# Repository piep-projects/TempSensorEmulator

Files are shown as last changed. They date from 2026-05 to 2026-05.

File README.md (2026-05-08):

# Wolf CHA-07 Außenfühler-Emulator

Simuliert den NTC-Außentemperaturfühler einer Wolf CHA-07/10/16/20 Monoblock-Wärmepumpe mittels digitalem Potentiometer. Ermöglicht Funktions- und Heizkurvtests unabhängig von der realen Außentemperatur.

→ Vollständige Dokumentation: [PROJECT_OVERVIEW.md](PROJECT_OVERVIEW.md) · [FDS.md](FDS.md)  
→ Projektseite: [projects.v-online.me](https://projects.v-online.me/projekt/wolf-cha-07-ausenfuhler-emulator/)

---

## Hardware

| Komponente | Modell |
|---|---|
| Mikrocontroller | LilyGo T-Display-S3 (ESP32-S3, 1,9" Display) |
| Digitalpotentiometer | Soldered DIGIPOT 50 kΩ nom. (MCP4018T-503, kalibriert ~46 kΩ) |
| Akku | LiPo 3,7 V / 700 mAh |
| Verbindung | I²C über QWIIC-Buchse |

## Verdrahtung

```
T-Display-S3          MCP4018 (DIGIPOT 50K)      Wolf CHA-07
─────────────         ─────────────────────      ─────────────
3,3 V      ────────── VCC
GND        ────────── GND
GPIO 18    ────────── SDA  (QWIIC)
GPIO 17    ────────── SCL  (QWIIC)
                       PW ─────────────────────── Fühler Klemme 1
                       PA ─────────────────────── Fühler Klemme 2
                       PB  offen (nicht auf GND geführt)
```

> **Ausgangspins:** Der Soldered-Breakout führt Pin B (PB) nicht auf GND — der nutzbare
> Widerstandspfad ist **PW ↔ PA**. Messung mit Multimeter ebenfalls an diesen beiden Pins.

## Sensor-Kennlinie

Wolf-Außenfühler Art.-Nr. 2748916 · NTC 5 kΩ bei 25 °C · B = 3977 K *(Schätzwert)*

| Temperatur | Widerstand | MCP4018-Schritt (PW↔PA) |
|---:|---:|---:|
| −15 °C | 39 499 Ω | 18 / 127 |
| −10 °C | 29 476 Ω | 46 / 127 |
| −5 °C | 22 237 Ω | 66 / 127 |
| 0 °C | 16 950 Ω | 81 / 127 |
| +5 °C | 13 047 Ω | 92 / 127 |
| +10 °C | 10 136 Ω | 100 / 127 |
| +20 °C | 6 277 Ω | 111 / 127 |
| +30 °C | 4 013 Ω | 117 / 127 |

## Bedienung

Tasten lösen **beim Loslassen** aus — kein Auto-Repeat.

| Taste | Kurz loslassen (< 3,5 s) | Lang halten + loslassen (≥ 3,5 s) |
|---|---|---|
| **BOOT** (GPIO 0) | −0,5 °C | WLAN-Portal öffnen |
| **KEY** (GPIO 14) | +0,5 °C | Deep Sleep |

Beim langen Halten erfolgt keine Temperaturänderung.

## Flashen

```bash
git clone https://github.com/piep-projects/TempSensorEmulator
cd TempSensorEmulator

# Logo für LittleFS aufbereiten (einmalig, benötigt Pillow)
pip install Pillow
python3 tools/png_to_littlefs.py

pio run -t uploadfs   # LittleFS-Image (Logo)
pio run -t upload     # Firmware
pio device monitor    # Serieller Monitor (115200 Baud)
```

> **16 MB Flash:** Das T-Display-S3 hat 16 MB Flash. Die `platformio.ini` setzt `board_upload.flash_size = 16MB` — ohne diesen Eintrag schlägt `uploadfs` fehl.

**Über die Workbench (RFC2217):**
```bash
pio run -t uploadfs --upload-port 'rfc2217://<host>:<port>'
pio run -t upload   --upload-port 'rfc2217://<host>:<port>'
```

## WLAN einrichten (WiFiManager Captive Portal)

Beim Start verbindet sich das Gerät **still** mit dem gespeicherten Netz (kein Blockieren).  
Das Captive Portal wird **auf Knopfdruck** gestartet:

1. **BOOT-Taste 3,5 s gedrückt halten** → Display zeigt WiFi-Setup-Screen
2. Handy mit **`CHA-Emulator`** (Passwort: `wolf1234`) verbinden
3. Browser öffnet sich **automatisch** → Heimnetz wählen, Passwort eingeben
4. Gerät verbindet sich und startet den Webserver

Danach: Temperatur per Browser unter `http://<IP>` einstellen.

## OTA-Update

Neue Firmware einspielen unter `http://<IP>/update`

## Kompatibilität

| Wärmepumpe | ab Baujahr | Fühler-Art.-Nr. |
|---|---|---|
| Wolf CHA-07 | 10/2018 | 2748916 |
| Wolf CHA-10 | 10/2018 | 2748916 |
| Wolf CHA-16 | 05/2023 | 2748916 |
| Wolf CHA-20 | 05/2023 | 2748916 |

## Projektstruktur

```
TempSensorEmulator/
├── src/
│   ├── main.cpp          # Haupt-Loop, Deep-Sleep, Zustands-Automat
│   ├── display.h/.cpp    # Alle vier Screens + Icons
│   ├── ntc.h             # NTC-Kennlinie, Formel
│   ├── mcp4018.h/.cpp    # I²C-Treiber MCP4018
│   ├── battery.h/.cpp    # ADC, Ladestand, Lade-Erkennung
│   ├── wifi_mgr.h/.cpp   # WiFiManager, Webserver, OTA
│   └── prefs.h/.cpp      # NVS-Persistenz
├── data/
│   └── logo.png          # piep projects Logo (LittleFS, Splash-Screen)
├── mockups/              # Display-Mockups (PNG)
├── datasheets/           # MCP4018-Datenblätter, Logo-Quelle
├── tools/
│   ├── png_to_littlefs.py    # Logo-Konvertierung
│   └── generate_mockups.py   # Screen-Mockups erzeugen
└── platformio.ini
```

*piep projects*

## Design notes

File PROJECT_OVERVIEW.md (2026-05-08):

# Wolf CHA-07 Außenfühler-Emulator — Projektübersicht

**Hersteller:** piep projects  
**Projekt:** TempSensorEmulator  
**Hardware:** LilyGo T-Display-S3 · Soldered DIGIPOT 50 kΩ · LiPo 700 mAh  
**Firmware:** Arduino / PlatformIO  
**Repository:** https://github.com/piep-projects/TempSensorEmulator

---

## Wozu dient dieses Gerät?

Der Außenfühler der Wolf CHA-07/10 Monoblock-Wärmepumpe ist ein passiver NTC-Widerstand (5 kΩ bei 25 °C, Art.-Nr. 2748916). Der Regler liest dessen Widerstand und steuert darüber die Heizkurve.

Dieses Gerät ersetzt den echten Sensor durch ein per Hand einstellbares **digitales Potentiometer**. Damit lässt sich die Wärmepumpe im Labor oder bei der Inbetriebnahme mit beliebigen Außentemperaturen testen — unabhängig vom tatsächlichen Wetter.

**Typische Anwendungsfälle:**
- Heizkurve bei Extremtemperaturen prüfen (z. B. −10 °C im Sommer)
- Regler-Reaktion auf Temperaturänderungen beobachten
- Inbetriebnahme ohne Außenfühler-Anschluss
- Firmware-Entwicklung und Systemtests

---

## Hardware-Übersicht

| Komponente | Modell | Funktion |
|---|---|---|
| Mikrocontroller | LilyGo T-Display-S3 (ESP32-S3) | Steuerung, Display, WiFi |
| Digitalpotentiometer | Soldered DIGIPOT 50 kΩ nom. (MCP4018T-503, kalibriert ~46 kΩ) | NTC-Widerstand simulieren |
| Akku | LiPo 3,7 V / 700 mAh | Mobiler Betrieb |
| Verbindung zum Regler | 2-Draht, an Fühleranschluss Wolf | Ersatz des echten Sensors |

### Pinbelegung (T-Display-S3 → MCP4018)

```
T-Display-S3          MCP4018 (DIGIPOT 50K)      Wolf CHA-07
─────────────         ─────────────────────      ─────────────
3,3 V      ────────── VCC
GND        ────────── GND
GPIO 18    ────────── SDA  (QWIIC)
GPIO 17    ────────── SCL  (QWIIC)
                       PW ─────────────────────── Fühler Klemme 1
                       PA ─────────────────────── Fühler Klemme 2
                       PB  offen (nicht auf GND geführt)
```

> **Ausgangspins:** Der Soldered-Breakout führt Pin B (PB) nicht auf GND — der nutzbare
> Widerstandspfad ist **PW ↔ PA**. Ausgangswiderstand messen: Multimeter an **PW und PA** anlegen
> (nicht PW/GND — Pin B ist nicht zugänglich).

---

## Display-Screens

Das Gerät hat vier Display-Zustände (Mockups in `mockups/`):

| Screen | Datei | Beschreibung |
|---|---|---|
| **Splash** | `screen_splash.png` | piep projects Logo weiß auf schwarz, Firmware-Version |
| **Main** | `screen_main.png` | Temperatur groß, Statusleiste oben, NTC-Info unten |
| **WiFi-Setup** | `screen_wifi_setup.png` | Captive-Portal-Anleitung (SSID, PW, 3 Schritte) |
| **Shutdown** | `screen_shutdown.png` | Roter Warnrahmen, Hinweis auf echten Fühler, Countdown |

---

## Features auf einen Blick

| Feature | Details |
|---|---|
| **Splash-Screen** | piep projects Logo (weiß auf schwarz) + Firmware-Version beim Start |
| **Temperaturanzeige** | −15 °C bis +30 °C, große Anzeige, Schritte 0,5 °C |
| **Tastensteuerung** | Auslösung beim Loslassen · BOOT loslassen < 3,5 s = −0,5 °C · KEY loslassen < 3,5 s = +0,5 °C · kein Auto-Repeat |
| **Deep Sleep** | KEY ≥ 3,5 s halten + loslassen → Stromsparmodus; beliebige Taste → Aufwachen |
| **WiFi on Demand** | BOOT ≥ 3,5 s halten + loslassen → Captive Portal; beim Start nur stilles Reconnect |
| **Batterieanzeige** | Ladestand in % + Icon; Blitz beim Laden |
| **Warnung** | < 15 % rot; < 5 % → automatisch Sleep |
| **Web-Interface** | Temperatur vom Handy/PC einstellen, Status, WLAN-Config |
| **OTA-Update** | Firmware drahtlos über Browser (`/update`) einspielen |
| **NVS-Speicher** | Temperatur + WLAN-Daten bleiben nach Neustart erhalten |

---

## Schnellstart

### 1. Hardware verbinden

Gemäß Verdrahtungstabelle oben. MCP4018 an QWIIC-Buchse des T-Display-S3.  
PW und PA an die Fühleranschlussklemmen der Wolf-Steuerung.

### 2. Firmware flashen

```bash
# Repository klonen
git clone https://github.com/piep-projects/TempSensorEmulator
cd TempSensorEmulator

# Logo für LittleFS vorbereiten (einmalig, benötigt Pillow)
pip install Pillow
python3 tools/png_to_littlefs.py

# LittleFS-Image hochladen
pio run -t uploadfs

# Firmware kompilieren und flashen
pio run -t upload

# Seriellen Monitor (optional, Diagnose)
pio device monitor
```

### 3. WLAN einrichten — WiFiManager Captive Portal

Das WLAN-Portal wird **auf Knopfdruck** gestartet (nicht automatisch beim Boot):

| Parameter | Wert |
|---|---|
| Auslöser | BOOT-Taste **3,5 s** halten |
| SSID | `CHA-Emulator` |
| Passwort | `wolf1234` |

**Ablauf:**
1. BOOT-Taste 3,5 s halten → Display wechselt auf WiFi-Setup-Screen
2. Handy mit `CHA-Emulator` verbinden
3. Browser öffnet sich **automatisch** (Captive Portal, wie Hotel-WLAN)
4. Heimnetz aus der Liste wählen + Passwort eingeben → Gerät verbindet sich

Beim nächsten Start verbindet sich das Gerät **still** mit dem gespeicherten Netz (kein Blockieren, kein Portal).

### 4. Temperatur einstellen

- **Am Gerät:** BOOT kurz drücken und loslassen = −0,5 °C · KEY kurz drücken und loslassen = +0,5 °C
- **Im Browser:** `http://<IP-Adresse>` → Temperatur per Webseite einstellen

### 5. OTA-Firmware-Update

Neue Firmware einspielen unter `http://<IP-Adresse>/update`

---

## Projektstruktur

```
TempSensorEmulator/
├── src/
│   ├── main.cpp              # Haupt-Loop, Zustands-Automat, Deep-Sleep
│   ├── display.h/.cpp        # Alle vier Screens + Icons
│   ├── ntc.h                 # NTC-Kennlinie, Formel
│   ├── mcp4018.h/.cpp        # I²C-Treiber MCP4018
│   ├── battery.h/.cpp        # ADC, Ladestand, Lade-Erkennung
│   ├── wifi_mgr.h/.cpp       # WiFiManager, Webserver, OTA
│   └── prefs.h/.cpp          # NVS-Persistenz
├── data/
│   └── logo.png              # piep projects Logo (LittleFS, Splash-Screen)
├── mockups/
│   ├── screen_splash.png     # Splash-Screen Mockup
│   ├── screen_main.png       # Haupt-Screen Mockup
│   ├── screen_wifi_setup.png # WiFi-Setup-Screen Mockup
│   └── screen_shutdown.png   # Shutdown-Screen Mockup
├── datasheets/
│   ├── piep-logo-projects1.png  # Logo-Quelle (Original)
│   ├── DIGIPOT-10K-MCP4018.pdf
│   └── SOLDERED_MCP4018_DATASHEET.pdf
├── tools/
│   ├── png_to_littlefs.py    # Logo für LittleFS aufbereiten
│   └── generate_mockups.py   # Screen-Mockups erzeugen (benötigt Pillow)
├── platformio.ini
├── README.md                 # Kurzreferenz
├── PROJECT_OVERVIEW.md       # dieses Dokument
├── FDS.md                    # Functional Design Specification
└── FEATURES.md               # Feature-Liste (Planungsphase)
```

---

## Bibliotheken (PlatformIO)

| Bibliothek | PlatformIO-ID | Version | Zweck |
|---|---|---|---|
| LovyanGFX | `lovyan03/LovyanGFX` | ^1.1.16 | Display-Treiber (ST7789, 8080-Bus) |
| WiFiManager | `tzapu/WiFiManager` | ^2.0.17 | WLAN-Konfiguration, Captive Portal |
| ElegantOTA | `ayushsharma82/ElegantOTA` | ^3.1.0 | OTA-Firmware-Update über Browser |
| ArduinoJson | `bblanchon/ArduinoJson` | ^7.0.0 | JSON für `/status`-Endpunkt |

> **Hinweis:** PNG-Dateien aus LittleFS werden per `malloc`/`drawPng()` geladen (kompatibel mit LovyanGFX ≥ 1.2.x).  
> Das T-Display-S3 hat 16 MB Flash — `board_upload.flash_size = 16MB` muss in `platformio.ini` gesetzt sein, da PlatformIO standardmäßig 8 MB annimmt.

---

## Kompatibilität

| Wärmepumpe | Baujahr | Fühler-Art.-Nr. |
|---|---|---|
| Wolf CHA-07 | ab 10/2018 | 2748916 |
| Wolf CHA-10 | ab 10/2018 | 2748916 |
| Wolf CHA-16 | ab 05/2023 | 2748916 |
| Wolf CHA-20 | ab 05/2023 | 2748916 |

---

## Dokumente

| Dokument | Inhalt |
|---|---|
| [README.md](README.md) | Kurzreferenz: Verdrahtung, Flashen, Bedienung |
| [FDS.md](FDS.md) | Functional Design Specification — vollständige technische Spezifikation |
| [FEATURES.md](FEATURES.md) | Feature-Liste der Planungsphase |
| [mockups/](mockups/) | Display-Screen-Mockups (PNG, 960×510) |
| [datasheets/](datasheets/) | MCP4018-Datenblätter, Logo-Quelldatei |

---

## Versionsverlauf

| Version | Datum | Änderungen |
|---|---|---|
| 1.0.0 | 2026-05-06 | Initiale Implementierung — Grundfunktion (NTC-Emulation, Display, Tasten) |
| 1.1.0 | 2026-05-06 | Batterie, Deep Sleep, WiFiManager Captive Portal, Web-Interface, OTA |
| 1.2.0 | 2026-05-06 | WiFi optional (on-demand via BOOT 3,5 s); KEY 3,5 s = Sleep; LittleFS-Fix |
| 1.3.0 | 2026-05-06 | Neues Logo (piep-logo-projects1); überarbeitetes Display-Design (gelbe Farbgebung, Knopf-Beschriftung); Release-Trigger-Tasten (kein Auto-Repeat); Shutdown-Countdown 10 s |
| 1.3.1 | 2026-05-06 | Splash-Logo-Bug behoben (LovyanGFX drawPng-Upscale-Artefakt); Mockup-Generator neu kalibriert (exakte Font-Metriken + Koordinaten) |
| 1.4.0 | 2026-05-07 | Display-Redesign: kein Logo in Kopfzeilen (nur Splash), Screens neu layoutet, Hint-Texte „lang:" statt „3.5s:", I²C-Status per Textfarbe, WiFi/Batterie-Icons vergrößert, Gradzeichen als Superscript |
| 1.4.1 | 2026-05-08 | Bugfix: Widerstandspfad W↔A statt W↔B (Pin B am Soldered-Breakout nicht auf GND); R_AB auf 46 000 Ω kalibriert (gemessen, Nennwert 50 kΩ ±20 %); Genauigkeit ±0,2 °C verifiziert |

---

*piep projects*

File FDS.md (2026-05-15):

# Functional Design Specification
## Wolf CHA-07 Außenfühler-Emulator

| Feld | Wert |
|---|---|
| Dokument | FDS-TempSensorEmulator |
| Version | 1.5 |
| Status | Freigegeben |
| Autor | piep projects |
| Datum | 2026-05-08 |
| Hardware | LilyGo T-Display-S3 · MCP4018T-503 · LiPo 700 mAh |
| Firmware | v1.4.2 |

---

## Inhaltsverzeichnis

1. [Zweck und Geltungsbereich](#1-zweck-und-geltungsbereich)
2. [Abkürzungen und Definitionen](#2-abkürzungen-und-definitionen)
3. [Systemübersicht](#3-systemübersicht)
4. [Hardware-Schnittstellen](#4-hardware-schnittstellen)
5. [Funktionale Anforderungen](#5-funktionale-anforderungen)
6. [Nicht-funktionale Anforderungen](#6-nicht-funktionale-anforderungen)
7. [Software-Architektur](#7-software-architektur)
8. [Zustands-Automat](#8-zustands-automat)
9. [Display-Spezifikation](#9-display-spezifikation)
10. [Web-Interface-Spezifikation](#10-web-interface-spezifikation)
11. [Kommunikations-Schnittstellen](#11-kommunikations-schnittstellen)
12. [Fehlverhalten und Ausnahmen](#12-fehlverhalten-und-ausnahmen)
13. [NTC-Kennlinien-Daten](#13-ntc-kennlinien-daten)
14. [Offene Punkte](#14-offene-punkte)

---

## 1. Zweck und Geltungsbereich

### 1.1 Zweck

Dieses Dokument beschreibt die vollständige funktionale Spezifikation des Wolf CHA-07 Außenfühler-Emulators. Es dient als verbindliche Grundlage für die Firmware-Implementierung.

### 1.2 Geltungsbereich

Das Dokument gilt für Firmware-Version v1.4.2 und die zugehörige Hardware-Revision 1.0.

### 1.3 Zweck des Geräts

Der Außentemperaturfühler der Wolf CHA-07/10/16/20 Monoblock-Wärmepumpe ist ein passiver NTC-Widerstand (5 kΩ bei 25 °C, Art.-Nr. 2748916). Das Gerät ersetzt diesen Sensor durch ein per Benutzer einstellbares digitales Potentiometer und ermöglicht damit Funktionstests des Wärmepumpen-Reglers bei beliebiger simulierter Außentemperatur.

---

## 2. Abkürzungen und Definitionen

| Begriff | Bedeutung |
|---|---|
| ADC | Analog-Digital-Wandler |
| AP | Access Point (WLAN-Hotspot) |
| FDS | Functional Design Specification |
| GPIO | General Purpose Input/Output |
| I²C | Inter-Integrated Circuit (serieller Bus) |
| LiPo | Lithium-Polymer-Akku |
| NTC | Negative Temperature Coefficient (Heißleiter) |
| NVS | Non-Volatile Storage (Flash-Speicher ESP32) |
| OTA | Over-The-Air (drahtloses Firmware-Update) |
| STA | Station Mode (WLAN-Client) |
| QWIIC | SparkFun I²C-Steckersystem (JST 1 mm, 4-polig) |

---

## 3. Systemübersicht

### 3.1 Blockdiagramm

```
┌────────────────────────────────────────────────────────┐
│                  LilyGo T-Display-S3                   │
│                                                        │
│  ┌──────────┐  I²C   ┌───────────────┐                │
│  │ ESP32-S3 │────────│  MCP4018T-503  │──PW──┐         │
│  │          │        │  Digipot 50kΩ  │      │ 2-Draht │
│  │          │        └───────────────┘──PB──┼────────── Wolf CHA-07
│  │          │                               │  Fühler  │
│  │          │  8080   ┌──────────────┐      │           │
│  │          │─────────│  ST7789 TFT  │      │           │
│  │          │         │  1,9"  320×170│      │           │
│  │          │         └──────────────┘      │           │
│  │          │  ADC    ┌──────────────┐      │           │
│  │          │─────────│  LiPo 700mAh │      │           │
│  │          │         │  + Lader     │      │           │
│  │          │         └──────────────┘      │           │
│  │          │  WiFi   ┌──────────────┐      │           │
│  │          │─────────│  802.11 b/g/n│      │           │
│  └──────────┘         └──────────────┘      │           │
│       │                                     │           │
│  GPIO 0 (BOOT)  GPIO 14 (KEY)              │           │
└────────────────────────────────────────────┼───────────┘
                                             │
                               Heizungsregler-Eingang
```

### 3.2 Betriebsmodi

| Modus | Beschreibung |
|---|---|
| Normal | Display an, Tasten aktiv, WiFi verbunden |
| AP-Setup | Kein WLAN konfiguriert; eigener Hotspot aktiv |
| Deep Sleep | Display aus, CPU im Tiefschlaf; Akku geschont |
| Laden | USB angeschlossen; Akku wird geladen; Betrieb normal |

---

## 4. Hardware-Schnittstellen

### 4.1 T-Display-S3 — GPIO-Belegung

| GPIO | Funktion | Richtung | Anmerkung |
|---:|---|---|---|
| 0 | Taste BOOT (−) | Eingang | Active LOW, interner Pull-up |
| 4 | Batterie-ADC | Eingang | Spannungsteiler ÷2 on-board |
| 5 | LCD Reset | Ausgang | Active LOW |
| 6 | LCD CS | Ausgang | |
| 7 | LCD DC | Ausgang | |
| 8 | LCD WR | Ausgang | |
| 9 | LCD RD | Ausgang | |
| 14 | Taste KEY (+) | Eingang | Active LOW, interner Pull-up |
| 15 | LCD Power Enable | Ausgang | Active HIGH |
| 43 | I²C SDA | Ein/Aus | QWIIC / STEMMA QT / EasyC |
| 44 | I²C SCL | Ausgang | QWIIC / STEMMA QT / EasyC |
| 38 | LCD Backlight | Ausgang | PWM, aktiv HIGH |
| 39–48 | LCD Datenbus D0–D7 | Ausgang | 8-Bit parallel 8080 |

### 4.2 MCP4018T-503 — Digitalpotentiometer

| Parameter | Wert |
|---|---|
| Typ | Single-End-Rheostat |
| Nennwiderstand R_AB | 50 000 Ω (kalibriert: 46 000 Ω — gemessen, innerhalb ±20 % Toleranz) |
| Wiper-Widerstand R_W | 75 Ω (typ.) |
| Auflösung | 128 Schritte (7-Bit) |
| I²C-Adresse | 0x2F (fest) |
| Betriebsspannung | 1,8 – 5,5 V (3,3 V) |
| I²C-Takt | 100 kHz |

**Ausgangspins (Soldered-Breakout):**

Der Soldered-Breakout führt Pin B **nicht** auf GND. Der genutzte Widerstandspfad ist
**PW (Wiper) ↔ PA (Terminal A)**. Messung und Heizungsanschluss erfolgen an diesen beiden Pins.
Pin PB bleibt offen.

**Widerstandsformel (W↔A-Pfad):**

```
R_WA(step) = (128 − step) × (R_AB / 128) + R_W
           = (128 − step) × 359,375 Ω + 75 Ω    (mit R_AB = 46 000 Ω)
```

**I²C-Schreibzugriff:**

```
START · 0x2F·WRITE · [step & 0x7F] · STOP
```

### 4.3 Batterie

| Parameter | Wert |
|---|---|
| Zellchemie | LiPo 1S |
| Nennspannung | 3,7 V |
| Kapazität | 700 mAh |
| Ladeschluss | 4,20 V |
| Entladeschluss | 3,20 V |
| Messung | GPIO 4 · ADC1 · Teiler ÷2 |
| Lade-Erkennung | USB-Spannung > Batterie-Spannung (Hysterese 0,1 V) |

**Spannungs-zu-Ladezustand-Kennlinie:**

| Spannung | SoC |
|---:|---:|
| 4,20 V | 100 % |
| 4,00 V | 85 % |
| 3,80 V | 60 % |
| 3,60 V | 30 % |
| 3,40 V | 10 % |
| 3,20 V | 0 % |

Interpolation linear zwischen Stützpunkten. Messung alle 10 s, gleitender Mittelwert über 4 Werte.

---

## 5. Funktionale Anforderungen

### FR-01 — Startsequenz

| ID | Anforderung |
|---|---|
| FR-01.1 | Nach dem Einschalten oder Aufwachen aus Deep Sleep zeigt das Gerät den Splash-Screen. |
| FR-01.2 | Der Splash-Screen zeigt das piep projects Logo (aus LittleFS, weiß auf schwarz) zentriert in der oberen Bildschirmhälfte. |
| FR-01.3 | Unterhalb des Logos erscheint der Text „TempSensorEmulator" in Gelb, darunter die Firmware-Version in Dunkelgrau. |
| FR-01.4 | Der Splash-Screen bleibt 1,5 Sekunden sichtbar. |
| FR-01.5 | Nach Ablauf der 1,5 Sekunden wechselt das Gerät selbstständig in den Hauptscreen. |
| FR-01.6 | Beim ersten Start ohne NVS-Daten wird als Starttemperatur +10,0 °C verwendet. |
| FR-01.7 | War ein Wert in NVS gespeichert, wird dieser unmittelbar nach dem Start an den MCP4018 übertragen — noch während des Splash-Screens. |

### FR-02 — Hauptscreen

| ID | Anforderung |
|---|---|
| FR-02.1 | Der Hauptscreen zeigt die aktuelle Simulationstemperatur in großer weißer Monospace-Schrift zentriert. Die Einheit „°C" wird in Gelb daneben angezeigt. |
| FR-02.2 | In der Info-Zeile (unten links) wird der berechnete NTC-Widerstand angezeigt (Gelb). Direkt daneben steht ein farbiger I²C-Statusblock (grün = OK, rot = Fehler) mit Beschriftung „I²C". |
| FR-02.3 | Die Statusleiste (oben) enthält: „TempSensorEmulator" (Gelb) links; WiFi-Balken-Icon + Batterie-Icon + % rechts. Die IP-Adresse wird nicht in der Statusleiste angezeigt. |
| FR-02.4 | Rechts oben (nahe dem physischen + Knopf): „Temp +" in Gelb, darunter „lang: AUS" in Weiß. Rechts unten (nahe dem physischen − Knopf): „Temp −" in Gelb, darunter „lang: WLAN" in Weiß. |
| FR-02.5 | Der Screen wird nach jeder Temperaturänderung vollständig neu gezeichnet. |
| FR-02.6 | Der MCP4018-Schrittwert (0–127) wird nicht mehr auf dem Display angezeigt. |

### FR-03 — Temperaturregelung über Tasten

Tasten-Auslösung erfolgt **beim Loslassen** (Release-Trigger), nicht beim Drücken.  
Es gibt kein Auto-Repeat — pro Drück-/Loslass-Zyklus wird genau eine Aktion ausgeführt.

| ID | Anforderung |
|---|---|
| FR-03.1 | Taste BOOT drücken und loslassen vor 3,5 s: Temperatur um −0,5 °C ändern. |
| FR-03.2 | Taste KEY drücken und loslassen vor 3,5 s: Temperatur um +0,5 °C ändern. |
| FR-03.3 | Wird eine Taste ≥ 3,5 s gehalten und dann losgelassen, wird die Sonderfunktion ausgelöst — keine Temperaturänderung. |
| FR-03.4 | Die Temperatur ist auf den Bereich −15,0 °C bis +30,0 °C begrenzt. |
| FR-03.5 | Jede Temperaturänderung wird sofort an den MCP4018 übertragen. |
| FR-03.6 | Jede Temperaturänderung wird in NVS gespeichert (max. alle 2 s, um Flash-Zyklen zu schonen). |

### FR-04 — NTC-Emulation (MCP4018)

| ID | Anforderung |
|---|---|
| FR-04.1 | Der Ziel-Widerstand wird nach der Steinhart-Hart-vereinfachten B-Formel berechnet: `R = R25 × exp(B × (1/T − 1/T25))` |
| FR-04.2 | Parameter: R25 = 5000 Ω, B = 3977 K, T25 = 298,15 K. |
| FR-04.3 | Der berechnete Widerstand wird in einen MCP4018-Schritt umgerechnet (W↔A-Pfad): `step = round(128 − (R − R_W) × 128 / R_AB)`, begrenzt auf 0–127. |
| FR-04.4 | Nach jedem Schreibzugriff wird der I²C-Rückgabewert geprüft; bei Fehler wird der I²C-Status im Display rot angezeigt. |
| FR-04.5 | Beim Start wird ein I²C-Scan durchgeführt; ist der MCP4018 nicht erreichbar, bleibt der Fehler dauerhaft angezeigt. |

### FR-05 — Persistenz (NVS)

| ID | Anforderung |
|---|---|
| FR-05.1 | Die zuletzt eingestellte Temperatur wird im NVS-Namespace `emulator` unter dem Schlüssel `temp` gespeichert. |
| FR-05.2 | WLAN-SSID und Passwort werden unter `wifi_ssid` und `wifi_pass` gespeichert. |
| FR-05.3 | Fehlt ein NVS-Schlüssel, wird der definierte Standardwert verwendet (Temp: +10,0 °C; WiFi: leer). |

### FR-06 — Deep Sleep / Energiesparmodus

| ID | Anforderung |
|---|---|
| FR-06.1 | Wird die KEY-Taste (+) ≥ 3,5 Sekunden gehalten und losgelassen, wechselt das Gerät in den Deep Sleep. Während des Haltens erfolgt keine Temperaturänderung. |
| FR-06.2 | Vor dem Einschlafen wird die Temperatur in NVS gespeichert. |
| FR-06.3 | Das Display wird vor dem Einschlafen ausgeschaltet (Backlight aus, Power-Enable LOW). |
| FR-06.4 | Das Gerät wacht durch Druck auf eine beliebige Taste auf (GPIO 0 oder GPIO 14 als Wakeup-Quelle). |
| FR-06.5 | Nach dem Aufwachen durchläuft das Gerät die vollständige Startsequenz (FR-01). |
| FR-06.6 | Der MCP4018 verliert im Deep Sleep seinen Zustand nicht (I²C-Pull-ups halten den Bus; Widerstand bleibt). |
| FR-06.7 | Fällt der Akku unter 5 % SoC, wechselt das Gerät automatisch in den Deep Sleep (mit Hinweis auf dem Display). |

### FR-07 — Batterieanzeige

| ID | Anforderung |
|---|---|
| FR-07.1 | Der Ladezustand wird als Prozentangabe und 5-stufiges Icon in der Statusleiste angezeigt. |
| FR-07.2 | Icon-Stufen: 0–20 % (leer), 21–40 %, 41–60 %, 61–80 %, 81–100 % (voll). |
| FR-07.3 | Wird das Gerät über USB geladen, erscheint ein Blitz-Symbol neben dem Batterie-Icon. |
| FR-07.4 | Bei < 15 % SoC blinkt das Icon im Sekundentakt (rot). |
| FR-07.5 | Bei < 5 % SoC erscheint eine Warnmeldung und das Gerät geht nach 10 Sekunden in Deep Sleep. |

### FR-08 — WiFi-Verbindung

Implementierung über **WiFiManager** (Library: `tzapu/WiFiManager`).

| ID | Anforderung |
|---|---|
| FR-08.1 | Das WiFi-Modul wird beim Start **nicht** aktiviert. Das Gerät läuft immer offline bis der Nutzer WiFi explizit startet. |
| FR-08.2 | WiFi wird **nur auf Knopfdruck** gestartet: BOOT-Taste ≥ 3,5 s halten und loslassen. Sind Credentials gespeichert, verbindet sich das Gerät direkt; andernfalls öffnet sich das Captive Portal. |
| FR-08.3 | ~~Entfallen~~ (in FR-08.2 zusammengefasst). |
| FR-08.4 | AP-Parameter: SSID `CHA-Emulator`, Passwort `wolf1234`, IP `192.168.4.1`. |
| FR-08.5 | Das Gerät zeigt während des AP-Modus den WiFi-Setup-Screen (§9.4) mit Verbindungsanleitung. |
| FR-08.6 | Das Handy verbindet sich mit dem AP; der Browser öffnet automatisch das Captive Portal (wie Hotel-WLAN). |
| FR-08.7 | Der Nutzer wählt sein Heimnetz; WiFiManager speichert die Daten; Webserver startet. |
| FR-08.8 | Nach erfolgreicher Verbindung zeigt die Statusleiste die zugewiesene IP-Adresse. |
| FR-08.9 | Im Deep Sleep wird das WiFi-Modul abgeschaltet. |

### FR-09 — Web-Interface

| ID | Anforderung |
|---|---|
| FR-09.1 | Der interne HTTP-Server läuft auf Port 80 (zusätzlich zum WiFiManager-Portal). |
| FR-09.2 | `GET /` liefert eine mobile HTML-Seite mit aktueller Temperatur, Widerstand, Batterie-SoC, Firmware-Version und IP. |
| FR-09.3 | Die HTML-Seite enthält Schaltflächen `[−]` und `[+]` zum Ändern der Temperatur in 0,5-°C-Schritten. |
| FR-09.4 | `GET /set?t=<wert>` setzt die Temperatur (Bereich −15 bis +30, Auflösung 0,5 °C); antwortet mit Redirect auf `/`. |
| FR-09.5 | `GET /status` antwortet mit JSON (siehe §10.2). |
| FR-09.6 | `/update` stellt die ElegantOTA-Seite für OTA-Updates bereit. |
| FR-09.7 | Die HTML-Seite ist mobilgerecht (Schriftgröße, Abstände für Touchbedienung). |

### FR-10 — OTA-Firmware-Update

| ID | Anforderung |
|---|---|
| FR-10.1 | OTA-Updates werden über ElegantOTA unter `http://<IP>/update` bereitgestellt. |
| FR-10.2 | Während des Updates zeigt das Display einen Ladebalken. |
| FR-10.3 | Nach erfolgreichem Update startet das Gerät automatisch neu. |
| FR-10.4 | Bei fehlerhaftem Update bleibt die alte Firmware aktiv (ESP32-Rollback-Mechanismus). |

---

## 6. Nicht-funktionale Anforderungen

### 6.1 Reaktionszeit

| Anforderung | Wert |
|---|---|
| Temperaturänderung → MCP4018-Update | < 50 ms |
| Tastendruck → Display-Update | < 100 ms |
| Web-Request `/set` → Antwort | < 500 ms |
| `/status` JSON-Antwort | < 100 ms |

### 6.2 Energieverbrauch (Schätzwerte)

| Betriebszustand | Strom | Laufzeit bei 700 mAh |
|---|---:|---:|
| Normal (Display an, WiFi) | ~110 mA | ~6,5 h |
| Normal (Display an, kein WiFi) | ~80 mA | ~8,5 h |
| Deep Sleep | ~15 µA | praktisch unbegrenzt |

### 6.3 Umgebungsbedingungen

Das Gerät ist für Innenraumeinsatz (Keller, Technikraum) ausgelegt.  
Betriebstemperatur: 0 °C – 50 °C · Luftfeuchtigkeit: nicht kondensierend.

### 6.4 Zuverlässigkeit

| Anforderung | Wert |
|---|---|
| NTC-Genauigkeit (nach B-Wert-Kalibrierung) | ±1 °C |
| MCP4018-Schritt-Auflösung | 359 Ω/Schritt (R_AB = 46 kΩ) → ±0,3 °C bei 0 °C |
| Messfehler nach Kalibrierung (Kontrollmessung) | ±0,2 °C bei 0 °C und 25 °C |
| I²C-Fehler | 3 Wiederholungsversuche, dann Fehler-Flag |

---

## 7. Software-Architektur

### 7.1 Modulübersicht

```
src/
├── main.cpp          Haupt-Loop · Zustands-Automat · Deep-Sleep-Logik
├── ntc.h             ntcOhm(tempC) · ohmToStep(R) — pure functions, kein State
├── mcp4018.h/.cpp    I²C-Init · mcp4018Set(step) · mcp4018Probe()
├── battery.h/.cpp    batteryReadVolt() · batteryPercent() · batteryCharging()
├── display.h/.cpp    drawSplash() · drawMain(state) · drawShutdown()
├── wifi_mgr.h/.cpp   wifiConnect() · wifiStartAP() · webServerSetup() · otaSetup()
└── prefs.h/.cpp      prefsLoad() · prefsSave() · prefsLoadWifi() · prefsSaveWifi()

data/
└── logo.png          Splash-Logo (LittleFS, 260×158 px, RGB)

tools/
└── png_to_littlefs.py  Logo-Konvertierung (einmalig, benötigt Pillow)
```

### 7.2 Abhängigkeiten (PlatformIO)

```ini
lib_deps =
    lovyan03/LovyanGFX @ ^1.1.16
    tzapu/WiFiManager @ ^2.0.17
    ayushsharma82/ElegantOTA @ ^3.1.0
    bblanchon/ArduinoJson @ ^7.0.0
```

LittleFS und NVS sind Teil des ESP32-Arduino-Frameworks (keine externe Abhängigkeit).

---

## 8. Zustands-Automat

```
        Einschalten / Aufwachen
               │
               ▼
         ┌──────────┐
         │  SPLASH  │ 1,5 s
         └────┬─────┘
              │ automatisch
              ▼
         ┌──────────┐   BOOT 3,5 s ──► ┌──────────────┐
         │   MAIN   │◄────────────────── │  WIFI_SETUP  │
         │          │   nach Portal      │   (AP-Modus) │
         └────┬─────┘                   └──────────────┘
              │ KEY 3,5 s
              │ oder SoC < 5 %
              ▼
         ┌──────────┐
         │  SLEEP   │ Deep Sleep (µA)
         └────┬─────┘
              │ Taste drücken
              └──────► SPLASH
```

Zustandsvariable `AppState` in `main.cpp`:  
`SPLASH → WIFI_SETUP → MAIN → SLEEP` (WiFiManager löst WIFI_SETUP bei Bedarf aus)

---

## 9. Display-Spezifikation

Display: ST7789V · 170 × 320 px · 8-Bit parallel · Rotation 1 (Querformat: 320 × 170)  
Bibliothek: LovyanGFX

### 9.1 Splash-Screen

```
┌────────────────────────────────────────────────────────────────┐  y=0
│                                                                 │
│                   ┌──────────────┐                             │
│                   │  piep  Logo  │  x=100, y=8, 120×73 px     │
│                   │  weiß/schwarz│  (scale 0.46 aus 260×158)  │
│                   └──────────────┘                             │
│                   TempSensorEmulator                           │  Gelb, y=92
│                        v1.3.0                                  │  Dunkelgrau, y=112
└────────────────────────────────────────────────────────────────┘  y=170
```

| Element | Farbe | Position |
|---|---|---|
| Logo (logo.png, LittleFS) | Weiß auf Schwarz | x=100, y=8, 120×73 px (scale 0.46) |
| „TempSensorEmulator" | Gelb | zentriert, y=92 |
| Firmware-Version | Dunkelgrau | zentriert, y=112 |

### 9.2 Hauptscreen

```
┌────────────────────────────────────────────────────────────────┐  y=0
│ [Logo] TempSensorEmulator    ))) 192.168.1.42  🔋 78%  Temp + │  Statusleiste
│                                                       3.5s:AUS │  y=26
├────────────────────────────────────────────────────────────────┤
│                                                                 │
│                      -5.5 °C                                   │  groß, zentriert
│                                                        Temp −  │
│                                                       3.5s:WLAN│  y=148
├────────────────────────────────────────────────────────────────┤
│  R = 22 237 Ω  ■ I²C                                          │  y=148..158
├────────────────────────────────────────────────────────────────┤
└────────────────────────────────────────────────────────────────┘  y=170
```

| Element | Farbe | Anmerkung |
|---|---|---|
| Logo (klein, transparent) | Weiß | Links in Statusleiste |
| „TempSensorEmulator" | Gelb | Rechts neben Logo |
| WiFi-Balken + IP | Weiß | Statusleiste Mitte |
| Batterie-Icon + % | Weiß / Rot (< 15 %) | Statusleiste rechts |
| „Temp +" / „3.5s: AUS" | Gelb / Weiß | Ganz rechts oben (phys. + Knopf) |
| Temperaturwert | Weiß | Groß, zentriert |
| „°C" | Gelb | Proportional zur Temperaturschrift |
| „Temp −" / „3.5s: WLAN" | Gelb / Weiß | Ganz rechts unten (phys. − Knopf) |
| „R = … Ω" | Gelb | Info-Zeile links |
| I²C-Statusblock + „I²C" | Grün/Rot + Gelb | Direkt rechts neben R-Wert |

### 9.3 Shutdown-Screen (vor Deep Sleep)

```
┌────────────────────────────────────────────────────────────────┐  gelber Rahmen
│ [Logo] TempSensorEmulator                                      │
│  ─────────────────────────────────────────────────────────── │
│              Gerät wird ausgeschaltet                          │  Gelb
│  ─────────────────────────────────────────────────────────── │
│         Letzte Temperatur:  −5.5 °C                           │  Grau
│                  Wert gespeichert.                             │  Grau
│  ─────────────────────────────────────────────────────────── │
│            Bitte echten Fühler wieder                          │  Gelb
│              an Heizung anschliessen!                          │  Gelb
│                    Ausschalten in  10 s …                      │  Dunkelgrau
└────────────────────────────────────────────────────────────────┘
```

Anzeige für 10 Sekunden (Countdown sichtbar), dann Deep Sleep.

### 9.4 WiFi-Setup-Screen (Captive Portal aktiv)

Wird angezeigt, solange WiFiManager im AP-Modus auf Konfiguration wartet.

```
┌────────────────────────────────────────────────────────────────┐  blauer Rahmen
│ [Logo] TempSensorEmulator                                      │
│  ─────────────────────────────────────────────────────────── │
│  ))) AP:  CHA-Emulator                                        │
│      PW:  wolf1234                                            │
│  ─────────────────────────────────────────────────────────── │
│  1. Handy mit "CHA-Emulator" verbinden                        │
│  2. Browser öffnet sich automatisch                           │
│  3. Heimnetz wählen + Passwort eingeben                       │
│                    Warte auf Verbindung …                      │
└────────────────────────────────────────────────────────────────┘
```

---

## 10. Web-Interface-Spezifikation

### 10.1 HTML-Hauptseite `GET /`

Responsive HTML5-Seite. Automatischer Refresh alle 10 Sekunden (`<meta http-equiv="refresh">`).

Inhalte:
- Titel „Wolf CHA-07 Außenfühler-Emulator"
- Titel „Wolf CHA-07 Außenfühler-Emulator"
- Aktuelle Temperatur (groß)
- Schaltflächen `[−]` und `[+]` (POST auf `/set`)
- Tabellarische Statuswerte: Widerstand, MCP4018-Schritt, Batterie, Firmware-Version, IP
- Formular zur WLAN-Konfiguration (SSID + Passwort + Schaltfläche „Speichern & Neustart")

### 10.2 JSON-Status `GET /status`

```json
{
  "temp_c":      -5.5,
  "resistance":  22237,
  "step":        57,
  "battery_pct": 78,
  "charging":    false,
  "wifi_ssid":   "MeinNetz",
  "ip":          "192.168.1.42",
  "fw_version":  "v1.2.0",
  "uptime_s":    3600
}
```

### 10.3 Temperatur setzen `GET /set?t=<wert>`

- Parameter `t`: Dezimalzahl, z. B. `-5.5`
- Auflösung: 0,5 °C (Wert wird auf nächsten 0,5-°C-Schritt gerundet)
- Bereich: −15,0 bis +30,0
- Antwort: HTTP 302 Redirect auf `/`
- Fehler (außerhalb Bereich): HTTP 400 mit Fehlermeldung

### 10.4 WLAN-Konfiguration `POST /wifi`

- Body: `ssid=<name>&pass=<passwort>`
- Aktion: In NVS speichern, HTTP 200 mit Hinweis auf Neustart, dann `ESP.restart()`

---

## 11. Kommunikations-Schnittstellen

### 11.1 I²C — MCP4018

| Parameter | Wert |
|---|---|
| Pins | SDA = GPIO 43, SCL = GPIO 44 |
| Frequenz | 100 kHz |
| Adresse | 0x2F (7-Bit, fest) |
| Protokoll | Single-Byte-Write: `[START][0x5E][step][STOP]` |
| Fehlerbehandlung | 3 Retries, danach Fehler-Flag |

### 11.2 ADC — Batterie

| Parameter | Wert |
|---|---|
| Pin | GPIO 4 (ADC1_CH3) |
| Auflösung | 12 Bit (0–4095) |
| Spannungsteiler | ÷2 (on-board) |
| Formel | `U_bat = ADC_raw × 3,3 V / 4095 × 2` |
| Mittelung | 4 Messungen, gleitender Mittelwert |
| Intervall | alle 10 s |

### 11.3 WiFi — HTTP

| Parameter | Wert |
|---|---|
| Standard | 802.11 b/g/n, 2,4 GHz |
| Port | 80 |
| Protokoll | HTTP/1.1 |
| Bibliothek | ESP32 WebServer (Arduino-Framework) |

---

## 12. Fehlverhalten und Ausnahmen

| Fehler | Erkennung | Reaktion |
|---|---|---|
| MCP4018 nicht erreichbar | I²C EndTransmission ≠ 0 | Rote Statusanzeige; 3 Retries; weiter laufen |
| LittleFS mount fehlt | `LittleFS.begin()` false | Splash ohne Logo; Text-Fallback |
| WiFi nicht gestartet | Default-Zustand beim Boot | Offline-Betrieb; Portal/Verbindung per BOOT ≥ 3,5 s |
| Temperatur außerhalb Bereich (Web) | Validierung in `/set` | HTTP 400 |
| Akku kritisch (< 5 %) | SoC-Berechnung | Shutdown-Screen, dann Deep Sleep |
| NVS leer | `nvs_get` not found | Standardwerte verwenden |

---

## 13. NTC-Kennlinien-Daten

**Sensor:** Wolf CHA-07 Außenfühler, Art.-Nr. 2748916  
**Typ:** NTC 5 kΩ bei 25 °C  
**B-Wert:** 3977 K *(Schätzwert — Herstellerangabe nicht veröffentlicht; mit Messung verifizieren)*

Schritte beziehen sich auf den **W↔A-Pfad** mit R_AB = 46 000 Ω (kalibriert).  
Kontrollmessung ergab ±0,2 °C Abweichung bei 0 °C und 25 °C.

| Temperatur | Widerstand | MCP4018-Schritt (W↔A) | Schrittweite* |
|---:|---:|---:|---:|
| −15 °C | 39 499 Ω | 18 | — |
| −10 °C | 29 476 Ω | 46 | ≈ 0,2 °C/Schritt |
| −5 °C | 22 237 Ω | 66 | ≈ 0,3 °C/Schritt |
| 0 °C | 16 950 Ω | 81 | ≈ 0,4 °C/Schritt |
| +5 °C | 13 047 Ω | 92 | ≈ 0,5 °C/Schritt |
| +10 °C | 10 136 Ω | 100 | ≈ 0,7 °C/Schritt |
| +15 °C | 7 943 Ω | 106 | ≈ 0,8 °C/Schritt |
| +20 °C | 6 277 Ω | 111 | ≈ 1,3 °C/Schritt |
| +25 °C | 5 000 Ω | 114 | ≈ 1,5 °C/Schritt |
| +30 °C | 4 013 Ω | 117 | ≈ 1,7 °C/Schritt |

*\* Temperaturauflösung pro MCP4018-Schritt — im relevanten Winterbereich (−10 bis +5 °C) besser als 0,5 °C.*

**Ausgangswiderstand messen:**  
Multimeter an **PW und PA** des Soldered-Breakouts anlegen (nicht PW/GND — Pin B nicht zugänglich).  
Gerät muss eingeschaltet und der MCP4018 per I²C programmiert sein.

**B-Wert verifizieren:**  
Sensor bei bekannter Temperatur (z. B. Eiswasser = 0 °C) mit Multimeter messen.  
Gemessenen Wert R und T = 273,15 K in `B = ln(R/R25) / (1/T − 1/T25)` einsetzen.  
Ergebnis in `ntc.h` als `NTC_B` eintragen.

---

## 14. Offene Punkte

| Nr. | Punkt | Priorität | Status |
|---|---|---|---|
| OP-01 | Wolf NTC B-Wert messtechnisch verifizieren | Hoch | Offen |
| OP-02 | WiFi-Ersteinrichtung | — | **Entschieden: on-demand via BOOT ≥ 3,5 s + Loslassen** |
| OP-02b | Laden-Erkennung: GPIO-Pin des Lader-IC prüfen (falls vorhanden) | Mittel | Offen |
| OP-03 | Display-Ausrichtung festlegen (USB-C nach oben oder unten) | Niedrig | Offen |
| OP-04 | Gehäuse / Halterung | Niedrig | Nicht spezifiziert |
| OP-05 | OTA-Passwortschutz (aktuell ohne Passwort) | Niedrig | Bewusst offen |
| OP-06 | Tasten-Verhalten Option B testen (Release-Trigger, kein Auto-Repeat) | Mittel | ✅ Erledigt v1.3.0 |
| OP-07 | Shutdown-Countdown (10 s) in Firmware implementieren und anzeigen | Mittel | ✅ Erledigt v1.3.0 |

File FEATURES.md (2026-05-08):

# Feature-Spezifikation — Wolf CHA-07 Außenfühler-Emulator

> **Hinweis:** Dieses Dokument ist die Planungsgrundlage. Die verbindliche Spezifikation steht in [FDS.md](FDS.md).

Version: 1.4.1  
Hardware: LilyGo T-Display-S3 · MCP4018T-503 (50 kΩ nom., kalibriert ~46 kΩ) · LiPo 700 mAh

---

## 1. Startsequenz

**Splash-Screen** (1,5 Sekunden):
- piep projects Logo (weiß auf schwarz) zentriert in oberer Bildschirmhälfte
- „TempSensorEmulator" in Gelb unterhalb des Logos
- Firmware-Version in Dunkelgrau darunter
- Keine Benutzeraktion erforderlich; danach automatisch → Hauptscreen

---

## 2. Hauptscreen

Layout (Querformat 320 × 170 px):

```
┌──────────────────────────────────────────────────────────────┐
│ TempSensorEmulator            ))) 🔋 78%       Temp +        │  ← Statusleiste
│                                                      lang:AUS│
├──────────────────────────────────────────────────────────────┤
│                                                               │
│                      -5.5 °C                         Temp −  │
│                                                    lang:WLAN │
├──────────────────────────────────────────────────────────────┤
│  R = 22 237 Ω  ■ I²C                                        │  ← Info
└──────────────────────────────────────────────────────────────┘
```

| Element | Beschreibung |
|---|---|
| „TempSensorEmulator" | Gelb; links in Statusleiste |
| Temperatur | Groß, weiß; °C in Gelb; ½-°C-Schritte |
| Widerstand | Berechneter NTC-Wert in Ω (Gelb) |
| I²C-Statusblock | Grün = OK, Rot = Fehler; direkt neben R-Wert |
| WiFi-Symbol | Signal-Balken + IP-Adresse; rot = getrennt |
| Batterie | Icon + Prozent; Blitz-Symbol beim Laden |
| Knopf-Hints | „Temp +" / „Temp −" gelb; Langdruck-Funktion weiß |

---

## 3. Temperaturregelung

Tasten lösen **beim Loslassen** aus — kein Auto-Repeat.

| Aktion | Funktion |
|---|---|
| BOOT loslassen (< 3,5 s) | −0,5 °C |
| KEY loslassen (< 3,5 s) | +0,5 °C |
| BOOT ≥ 3,5 s halten + loslassen | WLAN-Portal starten |
| KEY ≥ 3,5 s halten + loslassen | Deep Sleep |
| Bereich | −15 °C bis +30 °C |

Beim langen Halten erfolgt keine Temperaturänderung.  
Eingestellte Temperatur wird sofort an MCP4018 übertragen.  
Wert wird im Flash (NVS) gespeichert und nach Neustart wiederhergestellt.

---

## 4. Ein / Aus (Deep Sleep)

| Aktion | Funktion |
|---|---|
| KEY ≥ 3,5 s halten + loslassen | Shutdown-Screen (10 s), dann Deep Sleep |
| Beliebige Taste drücken | Aufwachen, Splash → Hauptscreen |

Im Deep Sleep: MCP4018 hält letzten Wert (I²C-Pegel fallen ab → Widerstand undefiniert).  
**Empfehlung:** Heizung vor dem Ausschalten auf echten Sensor umschalten.

---

## 5. Batterie

| Funktion | Details |
|---|---|
| Spannungsmessung | GPIO 4 (ADC, Teiler ÷2 on-board) |
| Ladestand-Anzeige | 0–100 %, 5-stufiges Icon |
| Laden-Erkennung | Spannung > 4,0 V und steigend → Blitz-Symbol |
| Kapazität | 700 mAh LiPo |
| Warnschwelle | < 15 % → Icon rot blinkend |
| Kritisch | < 5 % → automatisch Deep Sleep |

Spannungs-zu-Prozent-Kurve (LiPo typisch):

| Spannung | Ladezustand |
|---:|---:|
| 4,20 V | 100 % |
| 4,00 V | 85 % |
| 3,80 V | 60 % |
| 3,60 V | 30 % |
| 3,40 V | 10 % |
| 3,20 V | 0 % (Schutzabschaltung) |

---

## 6. WiFi

> **Entschieden:** WiFi-Konfiguration über **WiFiManager Captive Portal** (tzapu/WiFiManager).  
> Browser öffnet sich automatisch beim Verbinden mit dem AP — wie Hotel-WLAN.

### Verbindungsaufbau
1. Beim Start: stilles Reconnect (max. 10 s), kein Portal, kein Blockieren
2. Portal **nur auf Knopfdruck**: BOOT ≥ 3,5 s halten + loslassen
   - SSID: `CHA-Emulator`
   - Passwort: `wolf1234`
   - Browser öffnet sich automatisch → Netzauswahl + Passwort → Speichern

### Web-Interface (Port 80)

Aufrufbar über IP-Adresse im Browser (Handy oder PC).

**Hauptseite `/`**

```
┌─────────────────────────────────────────────┐
│        piep projects                           │
│   Wolf CHA-07 Außenfühler-Emulator          │
│                                             │
│   Temperatur          [ − ]  -5.5°C  [ + ] │
│   Widerstand          22 237 Ω              │
│   Batterie            78 %  (laden)         │
│   Firmware            v1.0.0                │
│   IP                  192.168.1.42          │
└─────────────────────────────────────────────┘
```

- Seite aktualisiert sich alle 5 Sekunden (auto-refresh)
- `[−]` / `[+]` senden HTTP-GET `/set?t=-6.0`
- Temperatur in 0,5-°C-Schritten einstellbar

**Endpunkte:**

| Endpunkt | Methode | Beschreibung |
|---|---|---|
| `/` | GET | Hauptseite (HTML) |
| `/set?t=<wert>` | GET | Temperatur setzen (−15 bis +30) |
| `/status` | GET | JSON: temp, resistance, step, battery_pct, charging, ip |
| `/update` | GET/POST | OTA-Firmware-Update (ElegantOTA) |

### OTA
- Bibliothek: **ElegantOTA**
- Erreichbar unter `http://<IP>/update`
- Kein Passwort (Gerät ist im lokalen Netz)

---

## 7. Software-Architektur

```
src/
  main.cpp          # Setup, Loop, Zustands-Automat, Deep-Sleep
  display.h/.cpp    # Splash, Main, WiFi-Setup, Shutdown + Icons
  ntc.h             # NTC-Kennlinie, ohmToStep()
  mcp4018.h/.cpp    # I²C-Treiber MCP4018
  battery.h/.cpp    # ADC-Messung, Ladestand, Laden-Erkennung
  wifi_mgr.h/.cpp   # WiFiManager, Web-Server, OTA
  prefs.h/.cpp      # NVS: Temperatur + WiFi-Credentials speichern
data/
  logo.png          # piep projects Logo weiß (für LittleFS)
mockups/
  screen_splash.png
  screen_main.png
  screen_wifi_setup.png
  screen_shutdown.png
```

---

## 8. Firmware-Versionsschema

`MAJOR.MINOR.PATCH` — z. B. `v1.3.0`  
Definiert als `#define FW_VERSION "v1.4.1"` in `config.h`.

---

## 9. Offene Punkte / Entscheidungen

| Punkt | Status |
|---|---|
| Wolf NTC B-Wert verifizieren | offen — Messung ausstehend |
| WiFi-Ersteinrichtung | ✅ WiFiManager Captive Portal |
| Display-Screens | ✅ 4 Screens: Splash, Main, WiFi-Setup, Shutdown |
| Logo auf Display | ✅ weiß auf schwarz; nur im Splash-Screen |
| Temperaturanzeige | ✅ große Mono-Schrift, °C in Gelb |
| Display-Ausrichtung (USB oben/unten) | offen — nicht festgelegt |
| Gehäuse / Halterung | nicht spezifiziert |

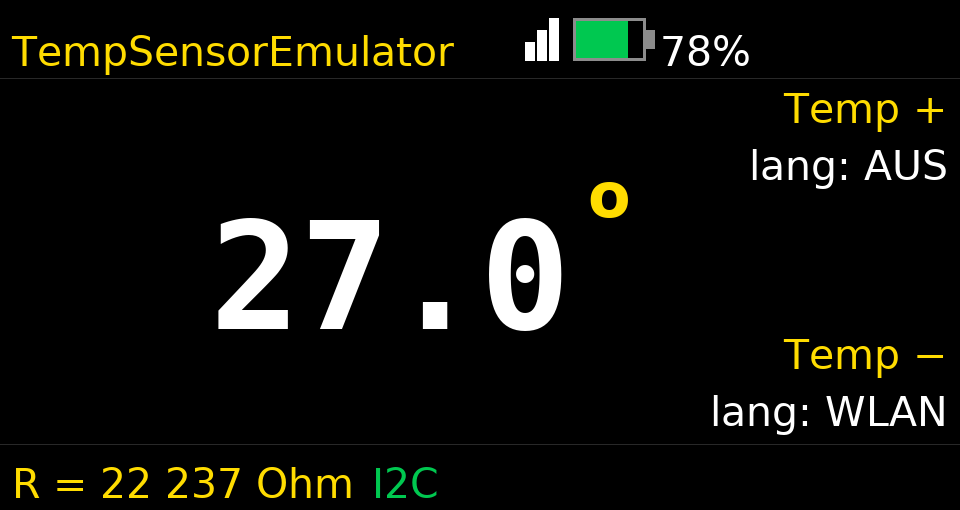
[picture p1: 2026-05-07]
mockups/screen_main.png

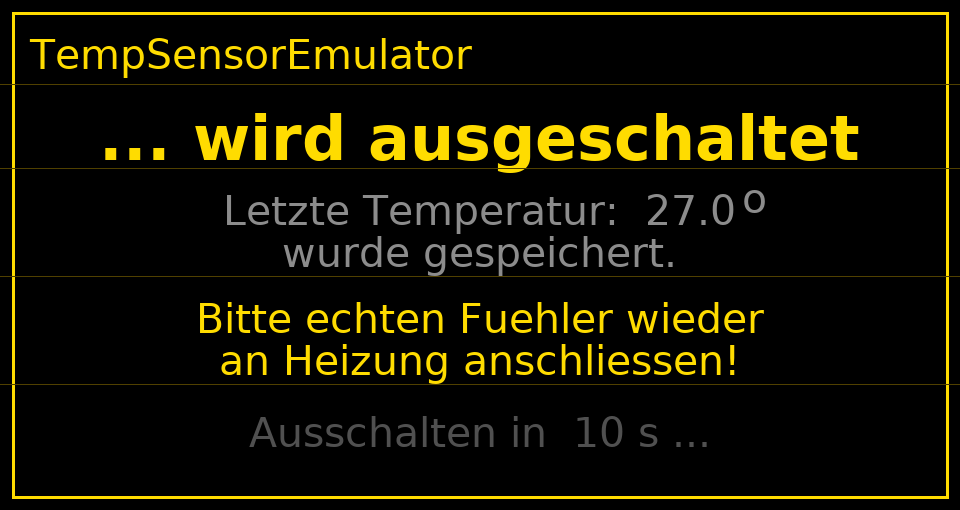
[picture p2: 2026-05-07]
mockups/screen_shutdown.png

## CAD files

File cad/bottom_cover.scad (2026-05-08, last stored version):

// ═══════════════════════════════════════════════════════════════════
//  Wolf CHA-07 Außenfühler-Emulator — DIGIPOT Untergehäuse
//  Datei: cad/bottom_cover.scad
//  Druck: FDM, PETG oder PLA, 0,2 mm Schichthöhe, 3 Wände
// ═══════════════════════════════════════════════════════════════════
//
//  Draufsicht (von unten gesehen):
//
//          Seite D  (kurz, 32 mm)  ← QWIIC-Schlitz
//          ┌──────────────────────┐
//          │                      │
//  Seite A │                      │ Seite C
//  (lang   │                      │ (lang
//  70 mm)  │                      │  70 mm)
//          │                      │
//          └──────────────────────┘
//          Seite B  (kurz, 32 mm)  ← beide Schrauben
//
//  Schrauben: horizontal, von außen durch Seite B, je 1 mm von A und C.
//  QWIIC:     Schlitz in Seite D, Kabel läuft von innen nach außen.

// ───────────────────────────────────────────────────────────────────
//  ❶  LILYGO T-DISPLAY-S3 GREY SHELL
// ───────────────────────────────────────────────────────────────────

shell_w = 70.0;   // [mm] Außenmaß lang  (A↔C, X-Achse)
shell_d = 32.0;   // [mm] Außenmaß kurz  (B↔D, Y-Achse)

// Schrauben auf Seite B — je 1 mm von Seite A bzw. Seite C
screw_ya      =  1.0;             // [mm] Abstand von Seite A  (Y = 1)
screw_yc      =  shell_d - 1.0;  // [mm] Abstand von Seite C  (Y = 31)

// Z-Höhe der Schrauben: wird unten im Berechnungsblock gesetzt.
// Bitte am Gerät nachmessen und ggf. überschreiben.

screw_d       =  2.2;   // [mm] Schaftbohrung M2
screw_head_d  =  4.2;   // [mm] Senkkopf-Ø (M2 = 3,8 mm)
screw_head_h  =  2.0;   // [mm] Senktiefe
boss_d        =  8.0;   // [mm] Boss-Ø (gibt 2,9 mm Wand um M2-Loch)
boss_pad      =  1.5;   // [mm] Boss-Überstand über Seite-B-Außenwand

// ───────────────────────────────────────────────────────────────────
//  ❷  SOLDERED DIGIPOT 50 kΩ (MCP4018T-503)
// ───────────────────────────────────────────────────────────────────

digipot_pcb_w  = 22.0;  // [mm] Platine X
digipot_pcb_d  = 22.0;  // [mm] Platine Y
digipot_pcb_h  =  2.0;  // [mm] Platinenstärke
digipot_comp_h =  5.0;  // [mm] Bauhöhe inkl. QWIIC-Buchse
digipot_margin =  1.5;  // [mm] Luft rund um Platine

// ───────────────────────────────────────────────────────────────────
//  ❸  QWIIC-KABELSCHLITZ  — Seite D (linke Stirnseite)
// ───────────────────────────────────────────────────────────────────

qwiic_slot_w  =  7.0;  // [mm] Breite in Y (Kabel + QWIIC-Buchse)
qwiic_slot_h  =  4.5;  // [mm] Höhe  in Z
// Y-Position: zentriert in Seite D
qwiic_slot_y  =  shell_d / 2 - qwiic_slot_w / 2;
// Z-Position: 1 mm über Bodenwand
qwiic_slot_z  =  wall_t + 1;

// ───────────────────────────────────────────────────────────────────
//  ❹  GEHÄUSE-PARAMETER
// ───────────────────────────────────────────────────────────────────

wall_t    = 2.0;
overlap_h = 3.0;
fit_clear = 0.3;

// ───────────────────────────────────────────────────────────────────
//  BERECHNETE GRÖßEN
// ───────────────────────────────────────────────────────────────────

inner_h = digipot_pcb_h + digipot_comp_h + 3.0;
total_h = inner_h + overlap_h;

// Schraubenhöhe: Kragen-Mitte — ggf. nachmessen und anpassen
screw_z = inner_h + overlap_h / 2;  // [mm]  ← MESSEN

outer_w = shell_w + 2 * wall_t;
outer_d = shell_d + 2 * wall_t;

collar_inner_w = shell_w + 2 * fit_clear;
collar_inner_d = shell_d + 2 * fit_clear;

// Standoff-Koordinaten (Platine zentriert in XY)
so_x0 = (shell_w - digipot_pcb_w) / 2 + digipot_margin * 0.4;
so_y0 = (shell_d - digipot_pcb_d) / 2 + digipot_margin * 0.4;
so_x1 = so_x0 + digipot_pcb_w - digipot_margin * 0.8;
so_y1 = so_y0 + digipot_pcb_d - digipot_margin * 0.8;

// Seite B: Außenfläche bei X = shell_w + wall_t
side_b_outer = shell_w + wall_t;

$fn = 48;

module so(x, y) { translate([x, y, wall_t]) cylinder(d=2.0, h=1.2); }

// ═══════════════════════════════════════════════════════════════════
//  HAUPTKÖRPER
// ═══════════════════════════════════════════════════════════════════

difference() {

    union() {

        // ── Kasten + Kragen, innen ausgehöhlt ──
        difference() {
            union() {
                translate([-wall_t, -wall_t, 0])
                    cube([outer_w, outer_d, inner_h]);
                translate([-wall_t, -wall_t, inner_h])
                    cube([outer_w, outer_d, overlap_h]);
            }
            // Innenraum Kasten
            translate([0, 0, wall_t])
                cube([shell_w, shell_d, inner_h - wall_t + 0.01]);
            // Innenraum Kragen
            translate([-fit_clear, -fit_clear, inner_h])
                cube([collar_inner_w, collar_inner_d, overlap_h + 1]);
        }

        // ── Boss-Zylinder Seite B — beide Schrauben ──
        // Ragen über Seite-B-Außenwand nach rechts (+X) heraus.
        translate([side_b_outer, screw_ya, screw_z])
            rotate([0, 90, 0])
            cylinder(d=boss_d, h=boss_pad);

        translate([side_b_outer, screw_yc, screw_z])
            rotate([0, 90, 0])
            cylinder(d=boss_d, h=boss_pad);

        // ── Standoffs für DIGIPOT-Platine ──
        so(so_x0, so_y0);
        so(so_x1, so_y0);
        so(so_x0, so_y1);
        so(so_x1, so_y1);
    }

    // ── Schraubenlöcher Seite B (von außen nach innen, -X-Richtung) ──
    // Startpunkt liegt 1 mm hinter der Boss-Außenfläche.
    _hole_start_x = side_b_outer + boss_pad + 1;
    _hole_depth   = boss_pad + wall_t - fit_clear + 2;

    translate([_hole_start_x, screw_ya, screw_z])
        rotate([0, -90, 0])
        cylinder(d=screw_d, h=_hole_depth);
    translate([_hole_start_x, screw_ya, screw_z])
        rotate([0, -90, 0])
        cylinder(d=screw_head_d, h=screw_head_h + 1);

    translate([_hole_start_x, screw_yc, screw_z])
        rotate([0, -90, 0])
        cylinder(d=screw_d, h=_hole_depth);
    translate([_hole_start_x, screw_yc, screw_z])
        rotate([0, -90, 0])
        cylinder(d=screw_head_d, h=screw_head_h + 1);

    // ── QWIIC-Schlitz Seite D (linke Stirnwand, -X-Richtung) ──
    translate([-wall_t - 1, qwiic_slot_y, qwiic_slot_z])
        cube([wall_t + 2, qwiic_slot_w, qwiic_slot_h]);
}

// ───────────────────────────────────────────────────────────────────
//  DEBUG: LilyGo-Referenzquader (* entfernen zum Einblenden)
// ───────────────────────────────────────────────────────────────────

*color("SteelBlue", 0.25)
    translate([0, 0, inner_h])
        cube([shell_w, shell_d, 14]);

// ───────────────────────────────────────────────────────────────────
//  SCHRAUBENZUGABE
//  boss_pad + (wall_t − fit_clear) = 1,5 + 1,7 = 3,2 mm
//  Beispiel: originale M2×5 → neue M2×8
// ───────────────────────────────────────────────────────────────────

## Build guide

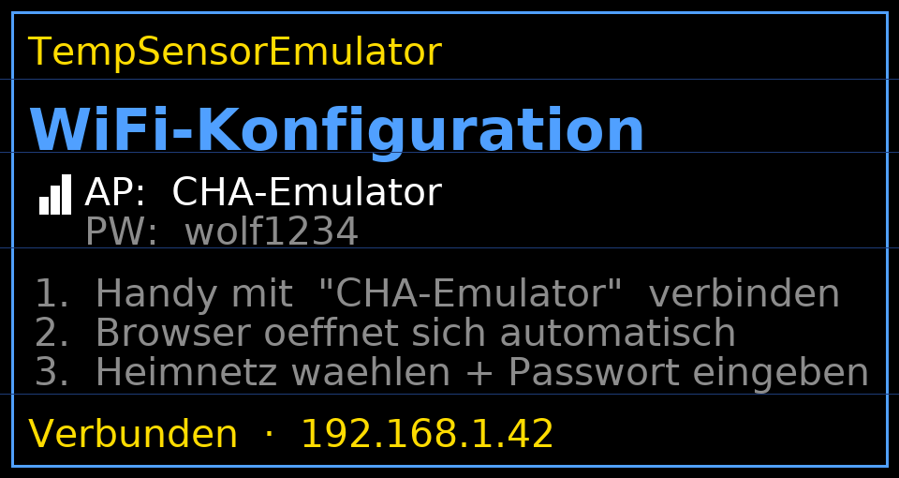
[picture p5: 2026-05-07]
mockups/screen_wifi_setup.png

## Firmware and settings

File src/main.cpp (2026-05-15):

// Wolf CHA-07 Aussenfuhler-Emulator  —  main.cpp
// piep design · v1.3.0

#include <Arduino.h>
#include "config.h"
#include "ntc.h"
#include "mcp4018.h"
#include "battery.h"
#include "prefs.h"
#include "display.h"
#include "wifi_mgr.h"

// ── Zustand ───────────────────────────────────────────────────
static float g_tempC        = TEMP_DEFAULT;
static bool  g_displayDirty = true;

// ── Button-Handling (Option B: Auslösung beim Loslassen) ──────
enum BtnEvent { BTN_NONE, BTN_SHORT, BTN_LONG };

struct Button {
    uint8_t  pin;
    uint32_t pressedAt;   // millis() beim Drücken (0 = nicht gedrückt)
    bool     prevPressed;
};

static Button btnMinus{ PIN_BTN_MINUS, 0, false };
static Button btnPlus { PIN_BTN_PLUS,  0, false };

// Erkennt Kurzdruck (<BTN_ACTION_MS) und Langdruck (>=BTN_ACTION_MS) beim Loslassen.
// Kein Auto-Repeat — eine Aktion pro Tastenbetätigung.
static BtnEvent pollButton(Button& b) {
    bool pressed = (digitalRead(b.pin) == LOW);

    if (pressed && !b.prevPressed) {
        b.pressedAt = millis();
    } else if (!pressed && b.prevPressed && b.pressedAt) {
        uint32_t held = millis() - b.pressedAt;
        b.pressedAt = 0;
        b.prevPressed = false;
        return (held >= BTN_ACTION_MS) ? BTN_LONG : BTN_SHORT;
    }

    b.prevPressed = pressed;
    return BTN_NONE;
}

// ── Sonderfunktionen ──────────────────────────────────────────

static void doSleep() {
    prefsFlush();
    for (int s = SHUTDOWN_COUNTDOWN_S; s >= 0; s--) {
        drawShutdown(g_tempC, s);
        if (s > 0) delay(1000);
    }
    displayBrightness(0);
    digitalWrite(PIN_POWER_ON, LOW);
    esp_sleep_enable_ext1_wakeup(
        (1ULL << PIN_BTN_MINUS) | (1ULL << PIN_BTN_PLUS),
        ESP_EXT1_WAKEUP_ANY_LOW);
    esp_deep_sleep_start();
}

static void doWifi() {
    wifiStartPortal();
    g_displayDirty = true;
}

// ── Temperatur setzen ─────────────────────────────────────────
static void applyTemp(float t) {
    g_tempC = t;
    mcp4018Set(ntcToStep(t));
    prefsSaveTemp(t);
    g_displayDirty = true;
    Serial.printf("T=%.1f°C  R=%.0fΩ  Step=%d  I2C=%s\n",
                  t, ntcOhm(t), ntcToStep(t),
                  mcp4018IsOk() ? "OK" : "ERR");
}

// ── Setup ─────────────────────────────────────────────────────
void setup() {
    Serial.begin(115200);
    Serial.println("\n=== Wolf CHA-07 Aussenfuhler-Emulator " FW_VERSION " ===");

    pinMode(PIN_BTN_MINUS, INPUT_PULLUP);
    pinMode(PIN_BTN_PLUS,  INPUT_PULLUP);

    displayBegin();
    drawSplash();
    delay(1500);

    bool i2cOk = mcp4018Begin(PIN_I2C_SDA, PIN_I2C_SCL);
    mcp4018ScanBus();
    Serial.printf("MCP4018: %s\n", i2cOk ? "OK" : "NICHT GEFUNDEN");

    prefsBegin();
    g_tempC = prefsLoadTemp();
    applyTemp(g_tempC);

    batteryBegin();

    wifiSetTempPtr(&g_tempC);
    wifiBegin();

    Serial.println("Kennlinie:");
    for (int t = -15; t <= 30; t += 5)
        Serial.printf("  %+3d°C → %.0fΩ → Step %d\n",
                      t, ntcOhm(t), ntcToStep(t));

    Serial.println("BOOT loslassen <3.5s = -0.5°C  |  KEY loslassen <3.5s = +0.5°C");
    Serial.println("BOOT >=3.5s loslassen = WLAN   |  KEY >=3.5s loslassen = Sleep");
}

// ── Loop ──────────────────────────────────────────────────────
void loop() {
    BtnEvent evMinus = pollButton(btnMinus);
    BtnEvent evPlus  = pollButton(btnPlus);

    if (evMinus == BTN_SHORT || evPlus == BTN_SHORT) {
        float d = (evMinus == BTN_SHORT ? -TEMP_STEP : 0.0f)
                + (evPlus  == BTN_SHORT ? +TEMP_STEP : 0.0f);
        float t = constrain(g_tempC + d, TEMP_MIN, TEMP_MAX);
        if (t != g_tempC) applyTemp(t);
    }

    if (evMinus == BTN_LONG) doWifi();
    if (evPlus  == BTN_LONG) doSleep();

    static uint32_t lastBat = 0;
    if (millis() - lastBat > BAT_UPDATE_MS) {
        batteryUpdate();
        lastBat = millis();
        g_displayDirty = true;

        if (batteryPercent() <= BAT_CRIT_PCT) {
            Serial.println("Akku kritisch — Deep Sleep");
            prefsFlush();
            drawShutdown(g_tempC, 3);
            delay(3000);
            displayBrightness(0);
            digitalWrite(PIN_POWER_ON, LOW);
            esp_sleep_enable_ext1_wakeup(
                (1ULL << PIN_BTN_MINUS) | (1ULL << PIN_BTN_PLUS),
                ESP_EXT1_WAKEUP_ANY_LOW);
            esp_deep_sleep_start();
        }
    }

    if (g_displayDirty) {
        String ip = wifiIP();
        drawMain(g_tempC, ntcOhm(g_tempC),
                 batteryPercent(), batteryCharging(),
                 ip.c_str(), mcp4018IsOk());
        g_displayDirty = false;
    }

    wifiLoop();
    delay(20);
}

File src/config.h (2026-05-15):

#pragma once

// ── Firmware ──────────────────────────────────────────────────
#define FW_VERSION      "v1.4.2"

// ── T-Display-S3 Tasten ───────────────────────────────────────
#define PIN_BTN_MINUS    0    // BOOT-Taste  (active LOW)
#define PIN_BTN_PLUS    14    // KEY-Taste   (active LOW)

// ── Display Power ─────────────────────────────────────────────
#define PIN_POWER_ON    15    // LCD Versorgung (active HIGH)

// ── LCD 8080-Parallelbus ──────────────────────────────────────
#define PIN_LCD_D0      39
#define PIN_LCD_D1      40
#define PIN_LCD_D2      41
#define PIN_LCD_D3      42
#define PIN_LCD_D4      45
#define PIN_LCD_D5      46
#define PIN_LCD_D6      47
#define PIN_LCD_D7      48
#define PIN_LCD_WR       8
#define PIN_LCD_RD       9
#define PIN_LCD_DC       7
#define PIN_LCD_CS       6
#define PIN_LCD_RST      5
#define PIN_LCD_BL      38

// ── I²C  QWIIC / STEMMA QT / EasyC ──────────────────────────
#define PIN_I2C_SDA     43
#define PIN_I2C_SCL     44

// ── Batterie ADC ─────────────────────────────────────────────
#define PIN_BAT_ADC      4    // Spannungsteiler ÷2 on-board

// ── MCP4018T-503 ─────────────────────────────────────────────
#define MCP4018_ADDR    0x2F
#define MCP_R_AB        46000.0f   // gemessen ~46 kΩ (Nennwert 50 kΩ, ±20% Toleranz)
#define MCP_R_W            75.0f   // Wiper-Widerstand (typ.)
#define MCP_STEPS           128    // Schritte (0 … 127)

// ── NTC Wolf CHA-07, Art. 2748916 ────────────────────────────
#define NTC_R25         5000.0f    // 5 kΩ bei 25 °C
#define NTC_B           3977.0f    // B-Wert (Schätzwert — verifizieren!)
#define NTC_T25_K        298.15f   // 25 °C in Kelvin

// ── Temperaturbereich ─────────────────────────────────────────
#define TEMP_MIN        -15.0f
#define TEMP_MAX         30.0f
#define TEMP_STEP         0.5f
#define TEMP_DEFAULT     10.0f

// ── Tasten-Timing ─────────────────────────────────────────────
// Option B: Auslösung beim Loslassen, kein Auto-Repeat
#define BTN_ACTION_MS    3500UL   // >= = Sonderfunktion beim Loslassen
#define SHUTDOWN_COUNTDOWN_S  10  // Sekunden Countdown vor Deep Sleep

// ── Batterie ──────────────────────────────────────────────────
#define BAT_WARN_PCT       15     // Icon blinkt rot
#define BAT_CRIT_PCT        5     // automatisch Deep Sleep
#define BAT_UPDATE_MS   10000UL   // Messintervall

// ── WiFi ──────────────────────────────────────────────────────
#define WIFI_AP_SSID    "CHA-Emulator"
#define WIFI_AP_PASS    "wolf1234"
#define WIFI_TIMEOUT_S     10     // Verbindungs-Timeout

// ── Webserver ─────────────────────────────────────────────────
#define WEB_PORT           80

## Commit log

2026-05-05 Initial implementation: Wolf CHA-07 Außenfühler-Emulator
    LilyGo T-Display-S3 + Soldered DIGIPOT 50kΩ (MCP4018T-503, I²C).
    Simulates NTC 5kΩ outdoor sensor (Wolf Art. 2748916) via digital
    potentiometer. Covers −15 °C to +30 °C with 0,5 °C resolution.
2026-05-05 Add feature specification and logo conversion tool
    Defines all planned features: splash screen with piep design logo,
    battery display with charging detection, deep sleep via dual-button
    long press, WiFi with AP fallback, web UI for remote temperature
    control, and ElegantOTA firmware updates.
2026-05-05 Add screen mockups and mockup generator
    Three PNG mockups (960x510, 3x scale) for all display states:
    - screen_splash.png: piep design logo + firmware version
    - screen_main.png: temperature, status bar, battery, WiFi, NTC info
    - screen_shutdown.png: deep sleep warning with sensor reminder
    Generated by tools/generate_mockups.py (requires Pillow).
2026-05-05 Update mockups and config: WiFiManager, larger temp, logo in statusbar
    - Main screen: temperature font larger (30→42pt), piep design logo
    replaces "Wolf CHA-07" text in top-left status bar
    - Add WiFi setup screen mockup with captive portal instructions
    - platformio.ini: add WiFiManager, ElegantOTA, ArduinoJson libraries
    - FDS: update FR-08/FR-09 for WiFiManager captive portal, add §9.4
    WiFi setup screen spec, close OP-02 (WiFi config decision)
2026-05-05 Update all documentation to reflect current design decisions
    README.md: rewrite with WiFiManager captive portal flow, updated
    project structure including mockups/, simplified and consistent.
    PROJECT_OVERVIEW.md: add Display-Screens table with all four screens,
    update WiFi section to captive portal, add libraries table, update
    project structure with mockups/ and generate_mockups.py.
    FEATURES.md: mark decisions as resolved (WiFiManager, 4 screens,
    white logo, large temperature font), add hint pointing to FDS.md
    as authoritative spec.
2026-05-05 Implement v1.1.0 firmware — all modules
    src/config.h — alle Pin-Definitionen, Konstanten, Schwellwerte
    src/ntc.h — NTC-Formel (header-only): ntcOhm(), ntcToStep()
    src/mcp4018.h/.cpp — I²C-Treiber MCP4018T-503 mit 3 Retries
    src/battery.h/.cpp — ADC-Messung, SoC-Kurve, Lade-Erkennung
    src/prefs.h/.cpp — NVS-Persistenz mit entprelltem Schreiben + prefsFlush()
    src/display.h/.cpp — LovyanGFX (8080-Bus), 4 Screens: Splash, Main,
    WiFi-Setup, Shutdown; Logo aus LittleFS
    src/wifi_mgr.h/.cpp — WiFiManager Captive Portal, WebServer /set
    /status /wifi-reset, ElegantOTA
    src/main.cpp — Zustands-Automat, Button-Auto-Repeat,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
    [battery.cpp, config.h, display.cpp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]
2026-05-06 Fix build: ArduinoJson package ID, 16MB flash upload, LovyanGFX PNG compat
    - platformio.ini: arduino-libraries/ArduinoJson → bblanchon/ArduinoJson
    - platformio.ini: add board_upload.flash_size = 16MB (T-Display-S3 has 16MB;
    PlatformIO defaults to 8MB causing uploadfs to fail)
    - display.cpp: replace drawPngFile(LittleFS, …) with malloc/read/drawPng()
    (drawPngFile with fs::LittleFSFS is abstract/broken in LovyanGFX ≥ 1.2.x)
    - Docs: library table with correct PlatformIO IDs, build notes, v1.1.0 date
    [display.cpp]
2026-05-06 v1.2.0: WiFi optional, new button mapping, logo fix, longer hold threshold
    - platformio.ini: add board_build.filesystem = littlefs — fixes logo not showing
    (uploadfs was creating SPIFFS image; LittleFS.begin() failed silently and
    formatted the partition empty, so /logo.png was never found)
    - config.h: BTN_ACTION_MS = 3500ms (was 2000ms), SLEEP_HOLD_MS/WIFI_TRIGGER_MS
    alias to BTN_ACTION_MS; FW_VERSION → v1.2.0
    - wifi_mgr: wifiBegin() no longer starts captive portal — connects to saved
    credentials only (short timeout), continues offline if unavailable;
    new wifiStartPortal() for on-demand use from button
    - main.cpp: remove both-button sleep trigger; BOOT held 3.5s → WiFi port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
    [config.h, display.cpp, main.cpp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]
2026-05-06 Docs: update all documents to v1.2.0
    - README.md: new button table (BOOT 3.5s=WLAN, KEY 3.5s=Sleep),
    updated WiFi setup section (on-demand portal)
    - PROJECT_OVERVIEW.md: features table, WLAN Schnellstart section,
    version history entry for v1.2.0
    - FDS.md: FR-01.4 splash 1.5s, FR-03.3b auto-repeat stop,
    FR-06.1 KEY 3.5s sleep, FR-08 WiFi on-demand, state machine diagram,
    display hint layout, bblanchon/ArduinoJson lib ID, error table
2026-05-06 v1.3.0: new logo, yellow UI, Option B buttons, 10s shutdown
    Display redesign: new piep-logo-projects1 on all 4 screens; yellow
    color scheme throughout; button hints (Temp+/Temp-/3.5s:AUS/3.5s:WLAN)
    added to main screen; I²C status block moved beside R=Ω value; step
    counter removed; shutdown screen uses yellow frame.
    Firmware: Option B release-trigger buttons — temperature changes only
    on release if held <3.5s, special function fires on release at ≥3.5s,
    no auto-repeat. Shutdown countdown extended to 10 seconds.
    Docs and mockups updated to match all changes.
    [config.h, display.cpp, main.cpp]
2026-05-06 Fix: Font6 has no letters — use Font4×2 for °C display
    Font6 in LovyanGFX only contains digits 0-9 and colon.
    'o' and 'C' were silently dropped. Switch to Font4 at textSize=2
    (32 px) with bottom-alignment to Font7 temperature digits (48 px).
    [display.cpp]
2026-05-06 Fix splash: use explicit scale=0.46 to avoid LovyanGFX upscale artifact
    drawPng with maxW > PNG natural width causes LovyanGFX to upscale,
    filling the display and covering the title text. Switching to explicit
    scale_x/scale_y=0.46f renders the 260×158 logo at 120×73px with a clean
    11px gap above the "TempSensorEmulator" label.
    [display.cpp]
2026-05-06 Mockups: fix font sizes and coordinates to match real display
    Previous mockups used 5.5–8px equivalent fonts for body text,
    making them look very different from the real device.
    Updated to accurate LovyanGFX bitmap font metrics:
    Font2=16px → F_F2=41px (largest that fits long strings)
    Font4=26px → F_F4=62px (largest that fits longest heading)
    Font7=48px → F_TEMP=207px (corrected for TrueType fill ratio)
    All coordinates match display.cpp exactly (1:1 mapping).
    Splash logo fixed: was scaling from original 1838px source,
    now uses the known rendered size (120×73 px).
2026-05-06 Docs: sync all documents to v1.3.0 / v1.3.1 state
    FDS.md:
    - Version header v1.2.0 → v1.3.0, status → Freigegeben
    - Geltungsbereich: v1.1.0 → v1.3.0
    - Splash-ASCII: v1.2.0 → v1.3.0, logo position exact (x=100 y=8 120×73px)
    - Shutdown-ASCII: fix "Wert gespeichert" line to match display.cpp
    - OP-06 + OP-07: marked as done in v1.3.0
    FEATURES.md:
    - Version 1.1 → 1.3
    - FW_VERSION: main.cpp → config.h, v1.0.0 → v1.3.0
    - Temperature unit color: Cyan → Gelb
    PROJECT_OVERVIEW.md:
    - Fix "halten für schnellen Lauf" → correct release-trigger description
    - Fix piep-design1.png → piep-logo-projects1.png in project tree
    - Add v1.3.1 changelog entry for splash fix + mockup recalibratio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
2026-05-06 Mockups: redesign all four screens for v1.4 layout
    - Main: remove logo from status bar, title left-aligned, WiFi+battery
    repositioned with spacing, temperature smaller, °C same size as digits,
    I2C status via text colour (no block), hint lines with larger gap
    - Splash: fix logo proportions (maintain original 2.07:1 AR)
    - Shutdown: remove logo, title left-aligned, '... wird ausgeschaltet',
    temperature line uses °C, combined 'wurde gespeichert' message
    - WiFi-Setup: remove logo, title left-aligned, 'WiFi-Konfiguration'
    left-aligned, IP line left-aligned in yellow
2026-05-06 v1.4.0: redesign all screens — no logo in headers, layout updates
    display.cpp / display.h:
    - drawMain: remove logo, title x=4, WiFi at x=175, battery at x=190/214,
    I2C status via text colour (green/red, no block),
    hint line spacing y=28/47 and y=110/129
    - drawWifiSetup(const char* ip=nullptr): remove logo, title x=10,
    WiFi-Konfiguration left-aligned, show IP in yellow when connected
    - drawShutdown: remove logo, title x=10, '... wird ausgeschaltet',
    'wurde gespeichert.' instead of 'Wert gespeichert.'
    wifi_mgr.cpp:
    - After portal connects, call drawWifiSetup(ip) for 1.5 s to confirm IP
    [display.cpp, wifi_mgr.cpp]
2026-05-06 Fix degree symbol: show only small 'o' superscript, drop 'C'; lang: hints
    - drawMain: replace large 'oC' (Font4×2) with small superscript 'o' (Font4×1)
    - Hint labels: '3.5s: AUS' → 'lang: AUS', '3.5s: WLAN' → 'lang: WLAN'
    - Mockup updated to match
    [display.cpp]
2026-05-07 v1.4.0: icons larger, degree symbol higher, docs sync to v1.4.0
    - Battery icon 20×10 → 24×14 px, WiFi bars 10 → 14 px tall
    - Degree superscript 10 px higher (main + shutdown screen)
    - Shutdown: temperature line split to render 'o' as superscript
    - FW_VERSION bumped to v1.4.0
    - Docs: piep design → piep projects, email removed from footers
    - FDS FR-02.3/02.4, FEATURES layout, version history updated
2026-05-08 v1.4.1: fix resistance path W↔A, calibrate R_AB to 46 kΩ
    - ntcToStep: corrected formula for W↔A path (Pin B not on GND on
    Soldered breakout); previous W↔B formula caused systematic error
    - config.h: MCP_R_AB 50000 → 46000 Ω (measured, within ±20% spec)
    - Verified ±0.2°C accuracy at 0°C and 25°C after calibration
    - All docs updated: wiring (PB→PA), Kennlinie steps, measurement pin
    guidance (PW↔PA), Versionsverlauf v1.4.1
    [config.h]
2026-05-08 Add DIGIPOT bottom cover CAD sketch and update .gitignore
    - cad/bottom_cover.scad: parametric OpenSCAD for bottom housing
    (DIGIPOT enclosure with collar overlap, screw bosses on side B,
    QWIIC slot on side D — replaced by Fusion 360 design)
    - datasheets/LILYGO-T-DISPLAY-S3_4.pdf: LilyGo T-Display-S3 datasheet
    - .gitignore: exclude wordpress/ folder
    [bottom_cover.scad]
2026-05-08 gitignore: exclude cad/ folder from tracking
    [bottom_cover.scad]
2026-05-15 v1.4.2: WiFi on-demand only, fix handleSet() wiper bug
    - wifiBegin() no longer attempts auto-connect at boot; WiFi starts only
    on explicit user request (BOOT >= 3.5 s). Eliminates HF noise from
    the 2.4 GHz transmitter coupling into the high-impedance digipot
    measurement path.
    - handleSet() in web interface now calls mcp4018Set() after updating
    g_tempC, so the MCP4018 wiper is actually moved on /set requests.
    - I2C pins corrected to GPIO 43/44 (QWIIC connector), mcp4018ScanBus()
    added, R_AB calibrated to 46 kΩ (previous commits, now documented).
    - FDS updated to v1.4.2, FR-08 rewritten for on-demand WiFi behavior.
    [config.h, main.cpp, mcp4018.cpp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]
